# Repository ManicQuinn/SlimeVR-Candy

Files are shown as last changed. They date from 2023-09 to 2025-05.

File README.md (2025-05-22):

# Candy-Case (Not Maintained Anymore due to moving on to my [Smol-Slimes Design](https://github.com/ManicQuinn/SlimeVR-Gremlin))
A Non-PCB case for SlimeVR trackers, over engineered and optimized for being compact. They're only 61.8mm(L)x60.5(W)x16.2mm(H) in size WITH strap loops, and only weigh about 50 grams with all the components inside and wired up(Including the battery I chose, your millage may vary).

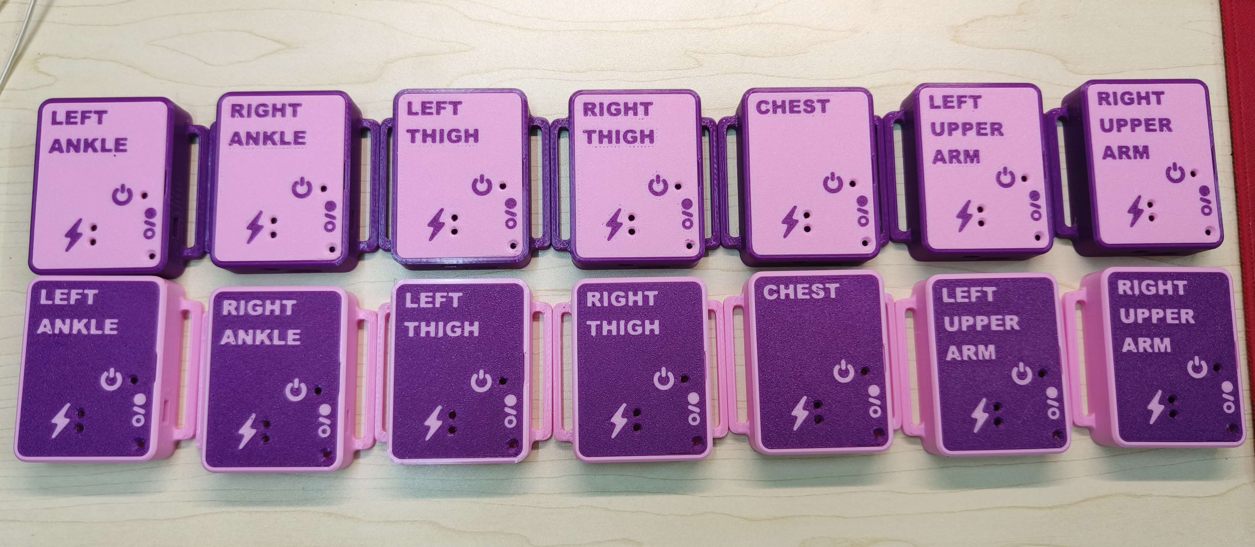
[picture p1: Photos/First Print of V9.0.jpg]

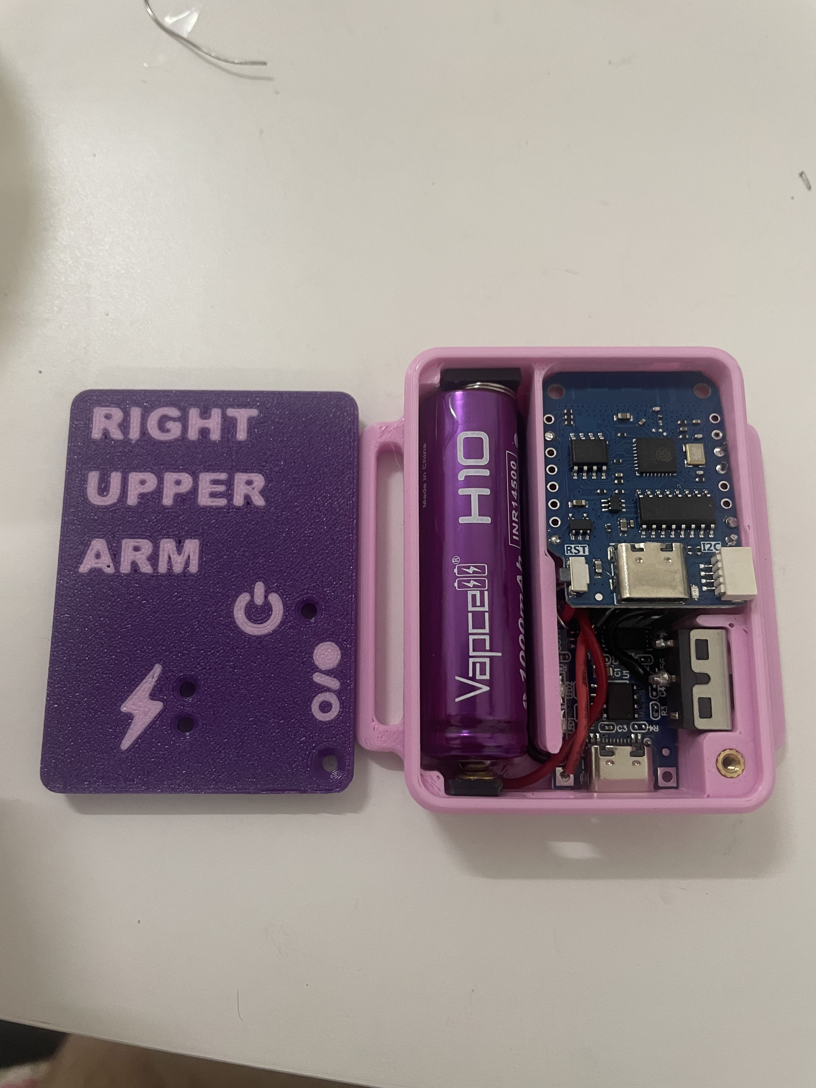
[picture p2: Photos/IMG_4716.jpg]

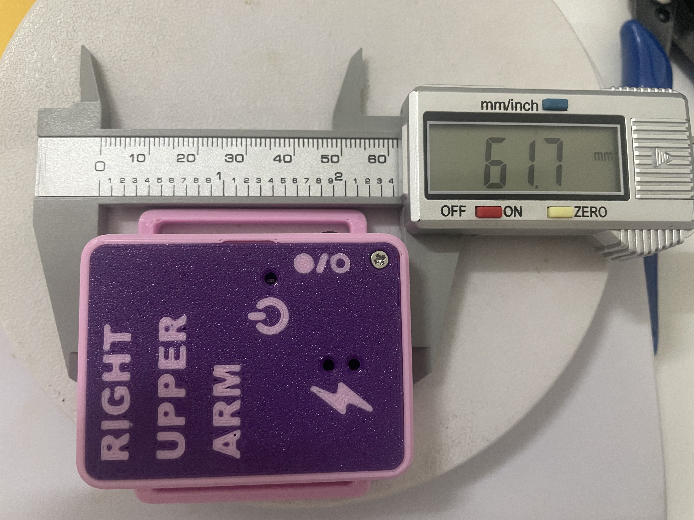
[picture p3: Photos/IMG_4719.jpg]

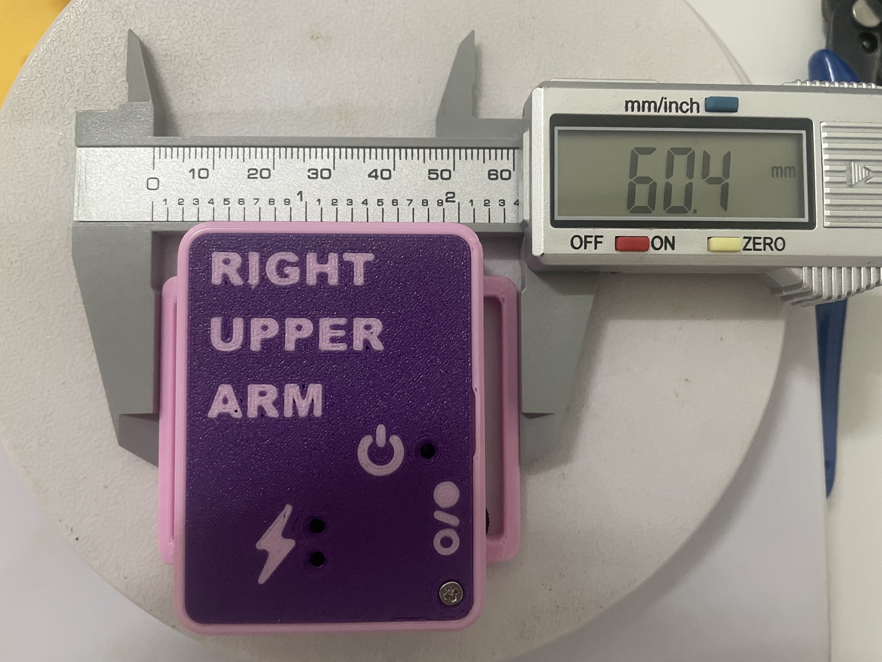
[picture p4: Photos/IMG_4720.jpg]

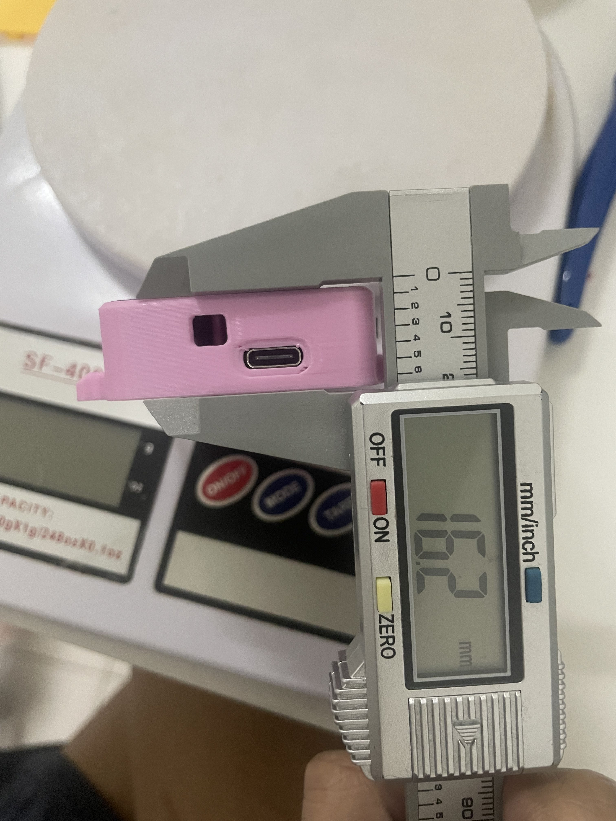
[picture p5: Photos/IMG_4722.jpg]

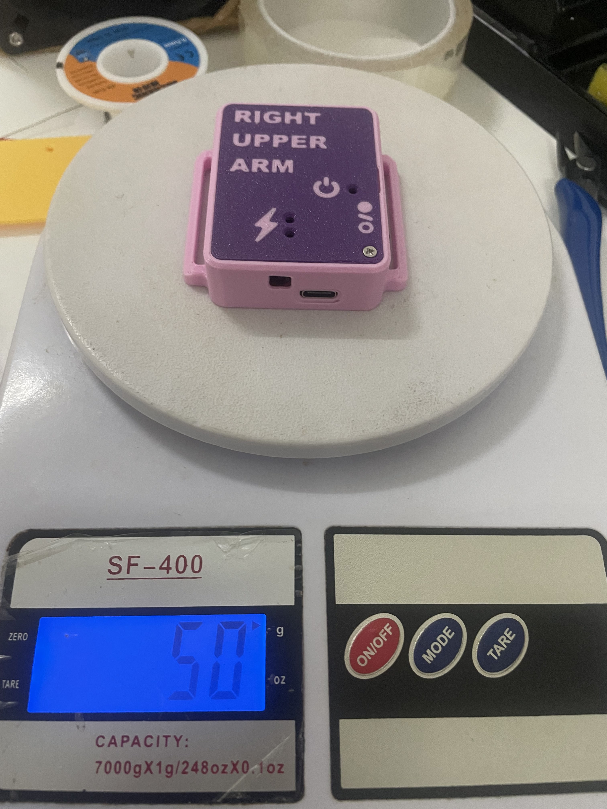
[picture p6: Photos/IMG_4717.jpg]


I've looked at every problem available to me at a technical level, from cable routing causing issues with the Wifi antenna, to a size problem when it comes to Non-PCB cases, the goal of this project was to be as optimized as I could. There were some issues I could not fix due to the design, and decided to compromise.

The issues are as follows:
1. The D1 Mini's USB port is inaccesible when you close up the case, this is due to me wanting the antenna to be close to the walls and away from all the cables. Not a huge issue in my opinion as you'll only need this to flash the firmware, calibration can be done wirelessly, a bit hard tho.
2. Soldering it is a lot harder than other cases due to the layout I chose as it is incredibly compact, and the IMU being under the D1 Mini makes it hard as well.
3. You will need to cut up a battery holder or some kind of battery contacts for your 14500 battery as these are designed with DIY battery contacts in mind, these can't be too thick either, I chose to cut one up with flush cutters and super glue them in place.
4. Double sided tape might be required for some parts, I used it for the IMU because cable tension kept pushing it into a non-flat position and also used tape on the lid to keep the switch from sliding into the case as the lid has a slight issue, you can also super glue the switch in, I opted not to.

Parts: 
1. Wemos D1 Mini V4.0
2. BMI160
3. TP4056 (Type C version)
4. SS12D10 Switch
5. Some kind of battery contacts, I used a cut up BH-311-1A AA Battery Holder
6. 14500 Lithium-Ion Battery 800-1000mAh, I used a Vapcell H10 as they're rated well
7. M2 screws, 8mm in length, Countersunk Flat Heads
8. M2 Heat threaded insert (OD)3.5mm (H)6mm

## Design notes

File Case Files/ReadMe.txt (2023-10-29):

These are source and STL files for the cases.

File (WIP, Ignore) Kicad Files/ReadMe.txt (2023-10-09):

These are WIP Kicad Files. These are pretty old and was made as a convenience, 
but there's quite a number of issues, including my lack of experience in PCB design,
decided to take a break on this until I learn more. These are based on an old form-factor too.

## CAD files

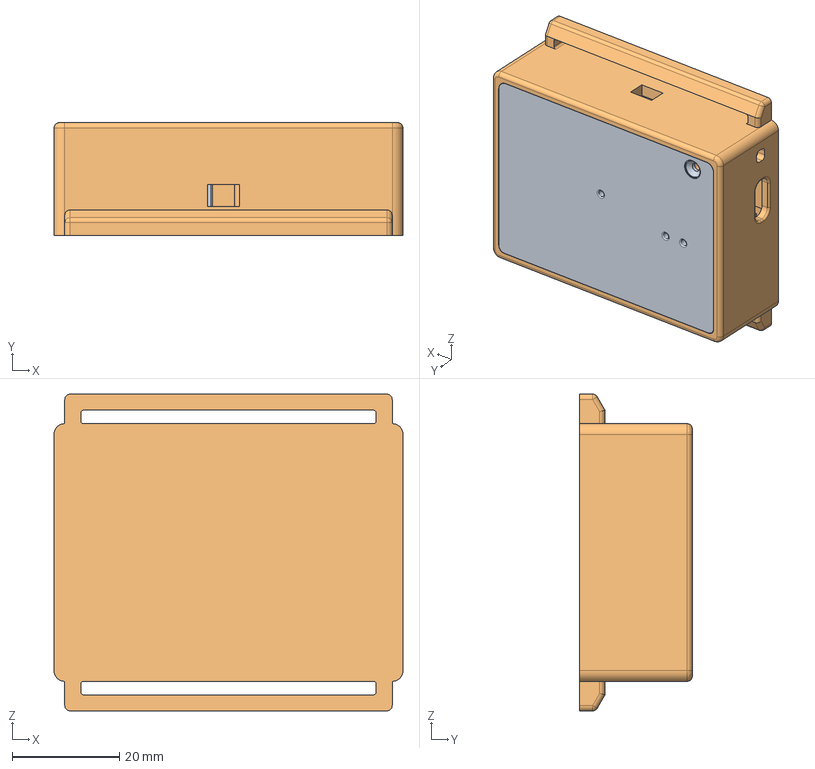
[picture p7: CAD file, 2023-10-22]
Case Files/V4.2 Open-Source.step
65.0 x 21.0 x 59.0 mm

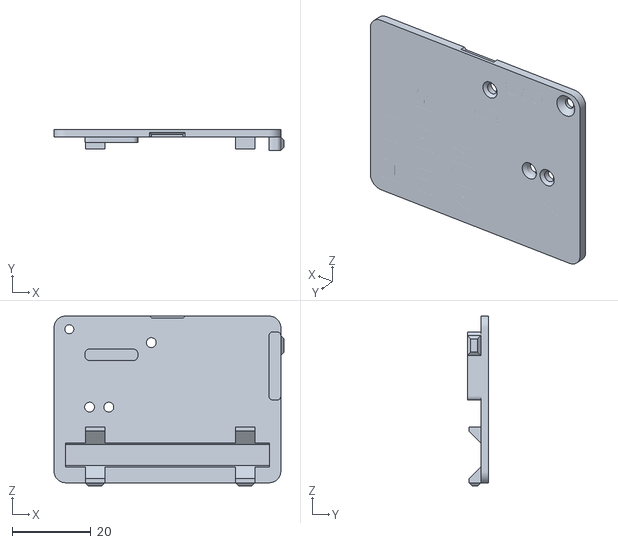
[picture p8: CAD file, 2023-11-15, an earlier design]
Case Files/V9.0/Lids with Labels/LUA Lid.stl
58.5 x 5.40 x 43.2

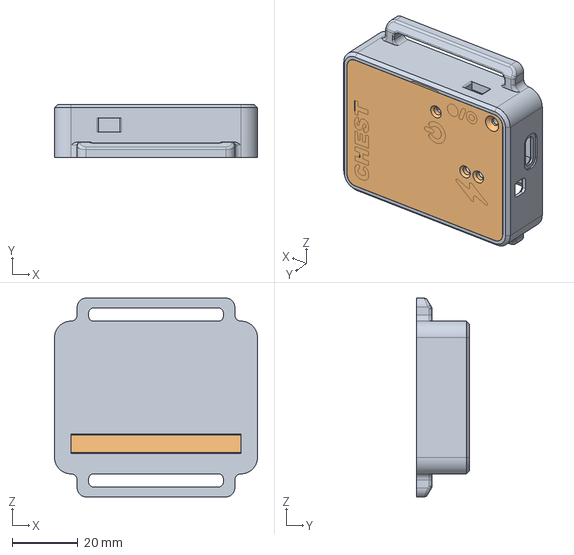
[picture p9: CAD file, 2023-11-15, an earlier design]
Case Files/V9.0/V9.0 Open-Source.step
61.8 x 16.2 x 60.5 mm

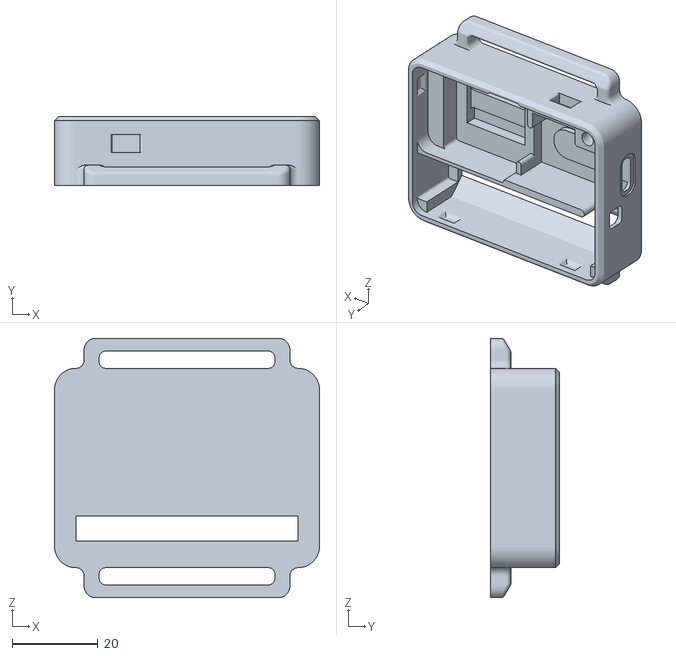
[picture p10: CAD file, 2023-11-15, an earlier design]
Case Files/V9.0/Body.stl
61.8 x 16.2 x 60.5

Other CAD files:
Case Files/V4.0 Open-Source.step
Case Files/V9.0/Lids with Labels/LT Lid.stl
Case Files/V9.0/Lids with Labels/LA Lid.stl
Case Files/V9.0/Lids with Labels/Chest Lid.stl
Case Files/V9.0/Lids with Labels/RUA Lid.stl
Case Files/V9.0/Lids with Labels/RT Lid.stl
Case Files/V9.0/Lids with Labels/RA Lid.stl
Case Files/V10.0/V10.0 Open-Source v10.f3d
Case Files/V9.0/V9.0 Open-Source.f3d

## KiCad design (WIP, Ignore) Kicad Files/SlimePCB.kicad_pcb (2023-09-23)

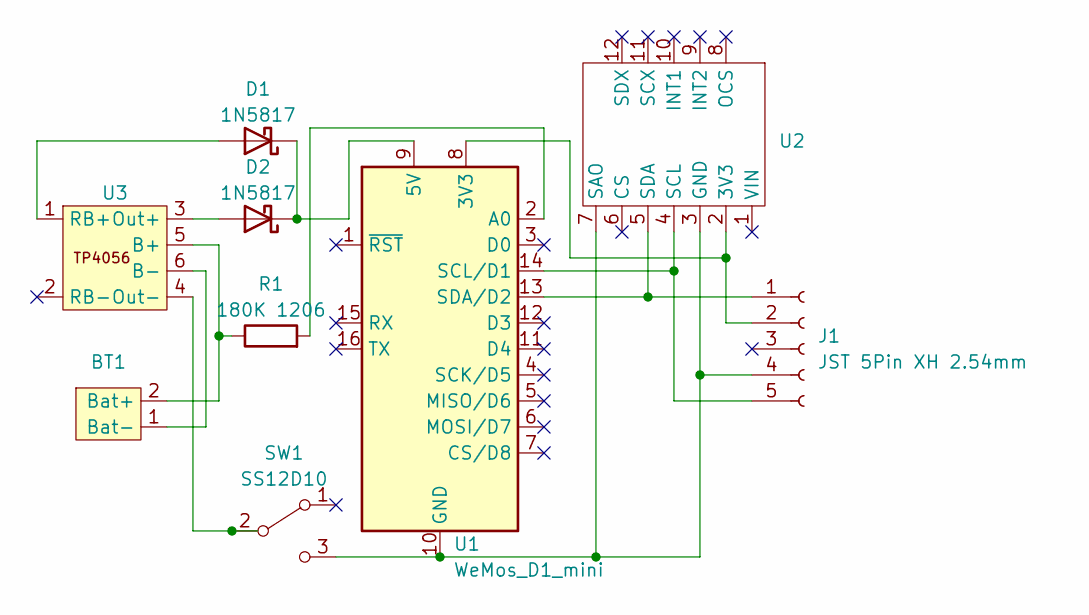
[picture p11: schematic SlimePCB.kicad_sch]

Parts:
BT1: Battery
D1, D2: 1N5817; DO-214AC
J1: JST 5Pin XH 2.54mm; JST_XH_S5B-XH-A_1x05_P2.50mm_Horizontal
R1: 180K 1206; R_1206_3216Metric_Pad1.30x1.75mm_HandSolder
SW1: SS12D10
U1: WeMos_D1_mini; WEMOS_D1_mini_light
U2: BMI160 module
U3: TP4056-18650

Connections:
unnamed: BT1.2 (Bat+), R1.1, U3.5 (B+)
unnamed: BT1.1 (Bat-), U3.6 (B-)
unnamed: D1.C (K), D2.C (K), U1.9 (5V)
unnamed: J1.1, U1.13 (SDA/D2), U2.5 (SDA)
unnamed: J1.2, U1.8 (3V3), U2.2 (3V3)
unnamed: J1.4, SW1.3 (C), U1.10 (GND), U2.3 (GND), U2.7 (SAO)
unnamed: J1.5, U1.14 (SCL/D1), U2.4 (SCL)
unnamed: SW1.2 (B), U3.4 (Out-)
unnamed: R1.2, U1.2 (A0)
unnamed: D2.A, U3.3 (Out+)
unnamed: D1.A, U3.1 (RB+)

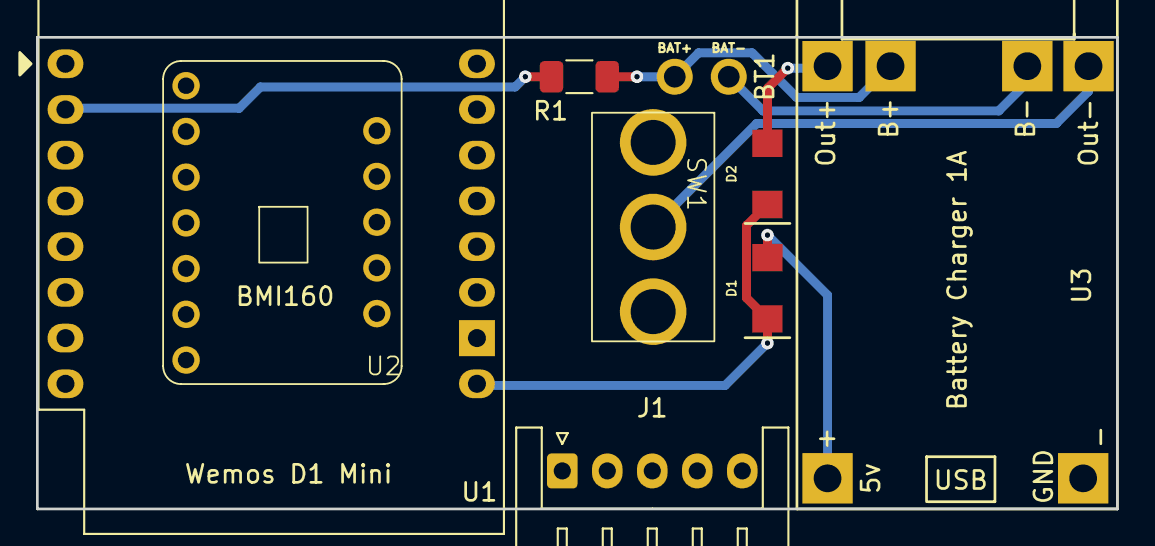
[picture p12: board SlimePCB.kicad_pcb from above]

Board: 2 copper layers, 60.0 x 26.2 mm, 9 parts (0 on the bottom side), 11 nets.

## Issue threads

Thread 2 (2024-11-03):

Little documentation on the inside of the case and parts

ItsKruml, 2024-11-03:
the title should be self explaining, but just in case:

Exact pats list: (diodes,resistors)

Documentation: (to few pictures of the case itself, like what it looks like below the board. and how the boards are positiond.

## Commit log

2023-09-23 Changed layout
    Things to do
    Learn how to add ground pours, signal return paths, stitching vias, ground vias
    [SlimePCB.kicad_pcb]
2023-09-23 Forgot Schematic
2023-10-09 Added 3D case files along with renaming Kicad Files to WIP
    [SlimeMania Case v1.0 Open-Source.f3d, SlimeMania Case v1.0 Open-Source.step, SlimePCB.kicad_pcb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]
2023-10-18 Updated to V2, changed quite a bit after first prototype.
    [SlimeMania Case v1.0 Open-Source.f3d, SlimeMania Case v1.0 Open-Source.step, V2 Case.stl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]
2023-10-21 Updated to V3.0, Thickened a lot of stuff, including strap loops, changed some stuff on the inside, including walls to hold in the D1 Mini.
    [V2 Case.stl, V2 Lid.stl, V2.0 Open-Sourced.f3d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]
2023-10-22 Updated to V4.0, moved to a permanent cable Aux design instead of removable JST, added some fillets in the case in the battery area, moved the screw stem for the lid so that you can use it to constra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
    [V3 Case Body.stl, V3 Lid.stl, V3.0.f3d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]
2023-10-22 Updated to V4.1, very minor update, shrinked the lid by 0.1mm.
    [V4 Lid.stl, V4.0 Open-Source.f3d, V4.1 Case Body.stl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]
2023-10-22 Updated to V4.2, changed fillet on screw hole to chamfer, added fillet to charging hole
    [V4.1 Case Body.stl, V4.1 Lid.stl, V4.1 Open-Source.f3d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]
2023-10-22 Updated to V4.3, very minor change, just adjusted the end stop for the screw so it doesn't go so deep.
    [V4.2 Case Body.stl, V4.2 Open-Source.f3d, V4.3 Case Body.stl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]
2023-10-23 Updated to V5.0. Important update from V4.0. Added fillets everywhere I could to make 3D printing easier, Fixed Switch Dimensions as they were very wrong before, adjusted D1 Mini height in the case t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
    [V4.3 Case Body.stl, V4.3 Lid.stl, V4.3 Open-Source.f3d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]
2023-10-28 Massive update from V5.0 as I finally had a test print of version 5, had to make a ton of changes to fix a ton of issues. Full change log below:
    Strap Loop was changed to be smaller and fit 38mm/1.5 inch straps, Lid was adjusted to 3mm thick, made tons of changes to tolerences of parts, moved screw hole, moved D1 LED hole as they were wrong before, adjusted size of LED holes, changed how the lid "clamped" onto some parts like D1 and TP4056, case is 1mm longer due to tolerence changes, adjusted tolerence of Lid, shortened stem of BMI160 and changed how TP4056 slides in.
    [V5.0 Case Body.stl, V5.0 Lid.stl, V5.0 Open-Source.f3d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]
2023-10-29 Updated to Ver.7.0: Redesigned the lid to still be 3mm but made a 1mm space for the battery as it wouldn't fit otherwise after rereviewing tolerences. Made a slight change in one of the fillets on th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
    [V6.0 Case Body.stl, V6.0 Lid.stl, V6.0 Open-Source.f3d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]
2023-11-10 Updated to V8.1. Bunch of tolerance changes from V7.0 and had a successful print, all parts fit but still needs more work, next version might be the final version, released as the true V1.0. Honestly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
    [V7.0 Case Body.stl, V7.0 Lid.stl, V7.0 Open-Source.f3d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]
2023-11-12 Updated to V8.3. Change log: D1 Mini V4.0 Tolerence reduced to fit better, TP4056 and D1 LED holes changed, D1 Mini LED still needs to be adjust further in next version. Aux Hole was moved higher up 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
    [V8.1 Body.stl, V8.1 Lid.stl, V8.1 Open-Source v6.step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]
2023-11-15 Final Update for Main tracker:
    - A lid "opening" gap on the edge of case to easily open the lid.
    - A "hole and peg" on the battery side so that it locks in this area, as I found that a single screw would not be enough because the battery would push against the lid when loose, worrying during fast movements.
    - Strap Loop increased gap by 1mm.
    - D1 Mini LED Hole adjusted as it is off by just a lil bit.
    - Adjusted the distance the screw hole is from the edge by 0.1mm to hopefully help with printing.
    - Battery gap on lid adjusted to 0.4mm instead of the initial 1mm.
    - Added fillets to switch hole to reduce strain on printer.
    - Text and Symbols added to all lids for body parts.
    [Body.stl, Chest Lid.stl, LA Lid.stl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]
2024-06-25 Added V10 f3d file
    [Body.stl, Chest Lid.stl, LA Lid.stl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]
2024-06-25 Changed the clamp measurements for chest strap.
    [V10.0 Open-Source v8.f3d, V10.0 Open-Source v9.f3d]
2024-07-05 Updated V10
    [V10.0 Open-Source v10.f3d, V10.0 Open-Source v9.f3d]
